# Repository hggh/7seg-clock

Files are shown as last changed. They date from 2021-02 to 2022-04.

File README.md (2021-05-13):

# seven segment clock with ambilight

 * 58x WS2812b 
 * ESP32
 * 74AHC125
 * XC6220 3.0V

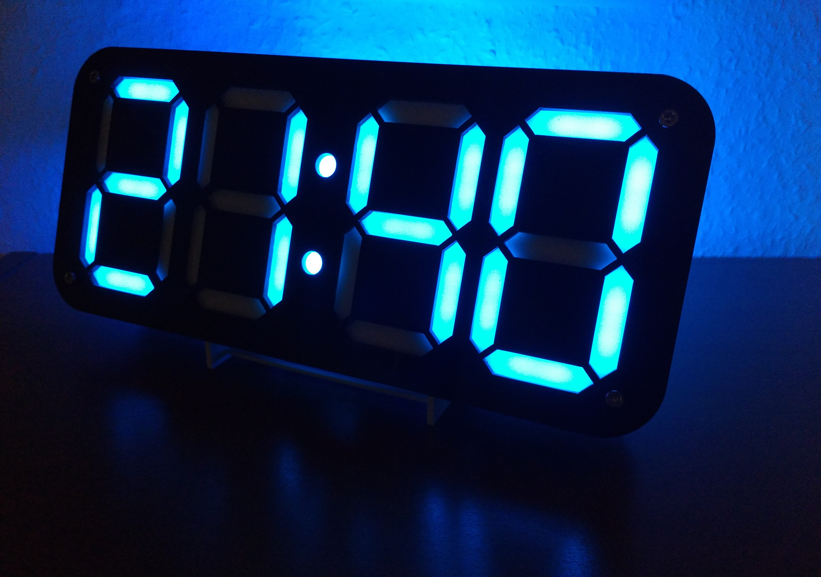
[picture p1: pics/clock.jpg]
7 Seg Clock 7 seg clock


To control the WS2812b LEDs the clock controller from wood clock light is used: https://github.com/hggh/wood-clock-light/tree/master/pcb/esp32-clock-base

### the base pcb for all ws2812b

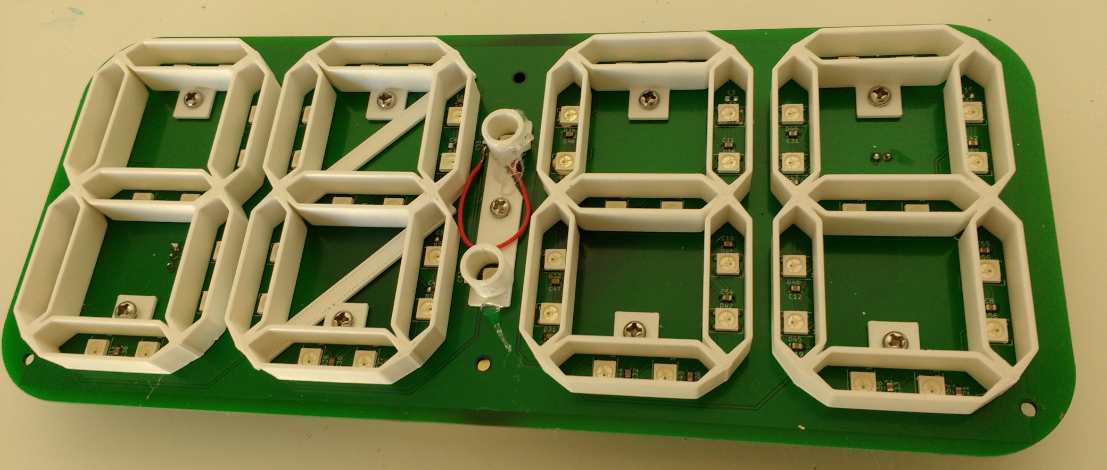
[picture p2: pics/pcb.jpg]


### ESP32 to control all LEDs

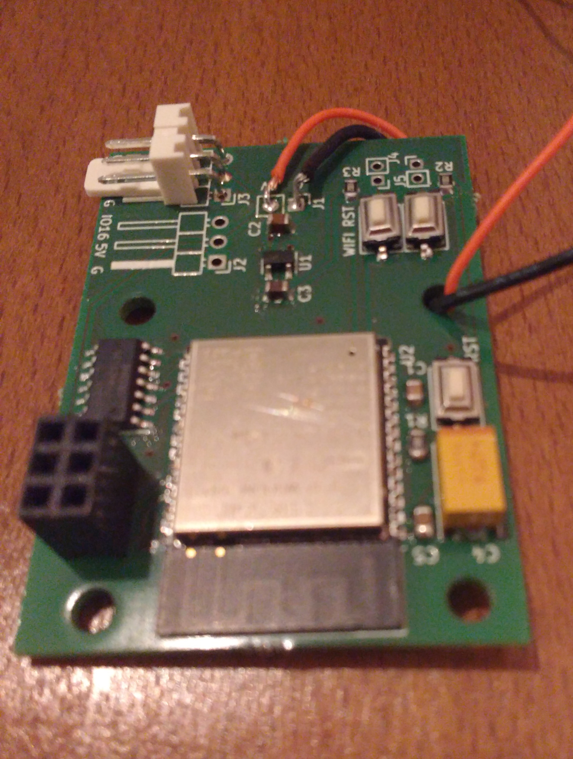
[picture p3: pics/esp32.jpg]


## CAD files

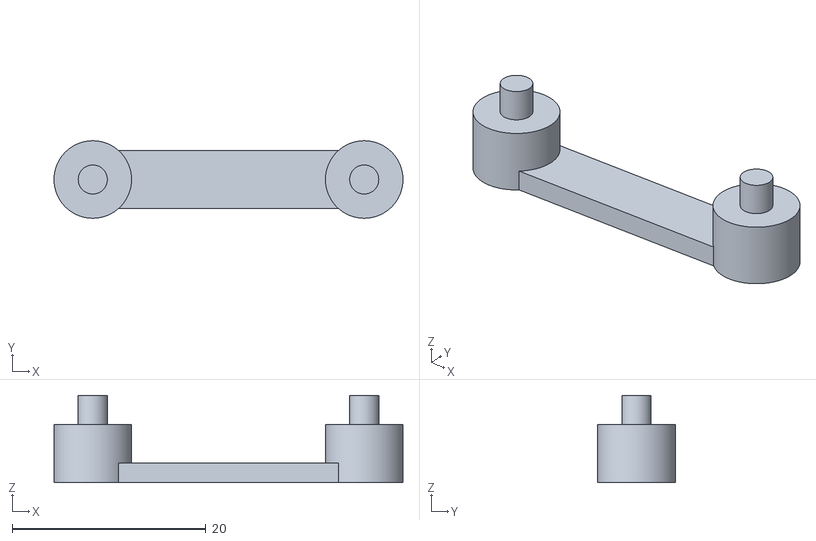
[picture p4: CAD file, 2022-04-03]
case/pcb-holder.stl
36.0 x 8.00 x 9.00

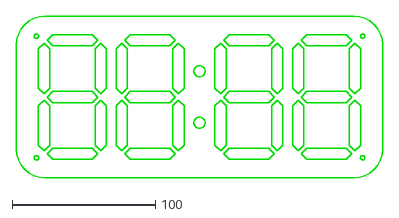
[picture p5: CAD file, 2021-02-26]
case/plexiglas-output/black_base_3mm.dxf
256.0 x 113.0

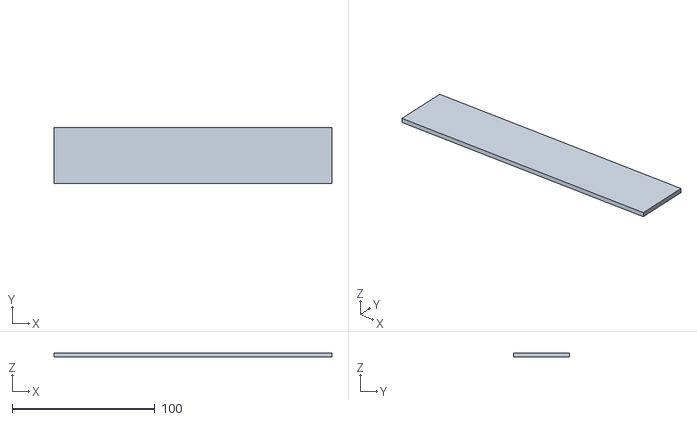
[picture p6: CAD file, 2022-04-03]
case/bottom.stl
195.0 x 39.0 x 3.00

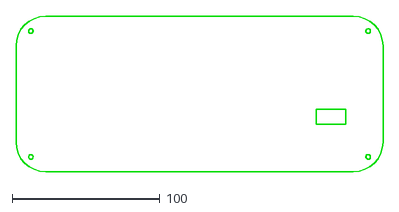
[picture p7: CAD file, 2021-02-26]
case/plexiglas-output/black_back_case_3mm.dxf
248.0 x 105.0

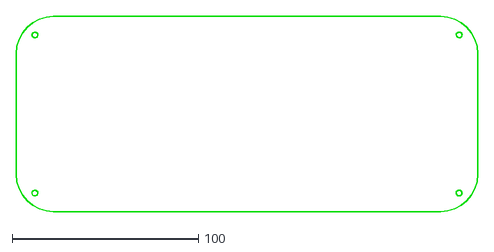
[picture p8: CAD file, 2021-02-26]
case/plexiglas-output/white_opal_3mm.dxf
248.0 x 105.0

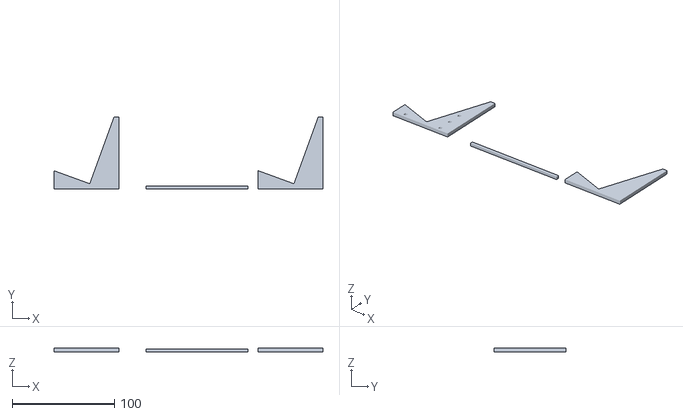
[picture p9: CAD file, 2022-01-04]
case/stand.stl
263.5 x 70.2 x 3.70

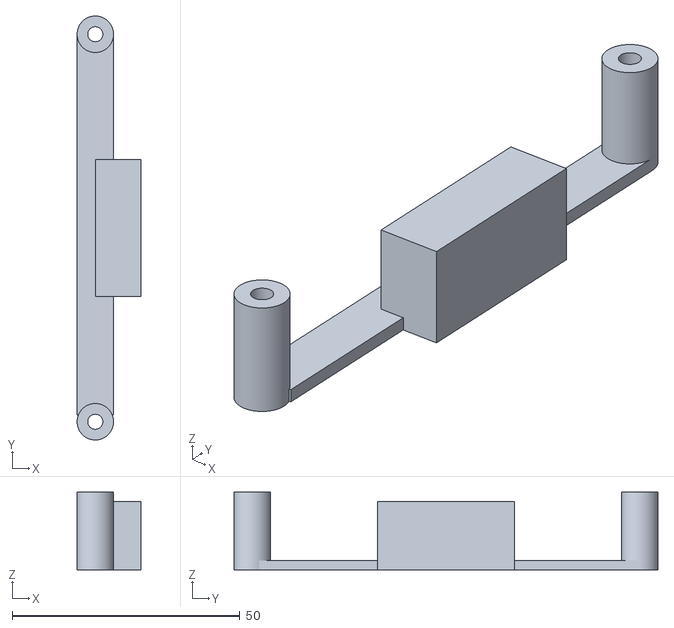
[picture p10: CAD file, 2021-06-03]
case/holder-case-wall.stl
14.0 x 93.0 x 17.0

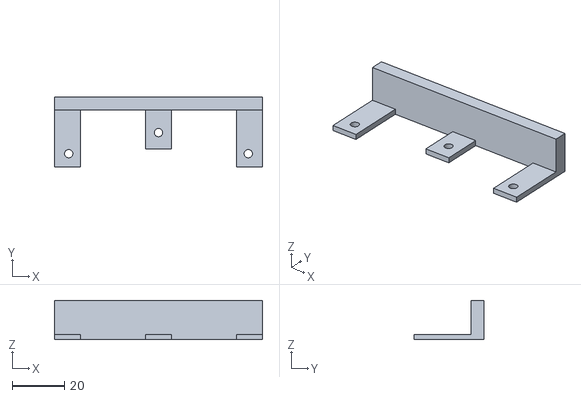
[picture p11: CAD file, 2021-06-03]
case/wall_mount_top.stl
80.0 x 27.0 x 15.0

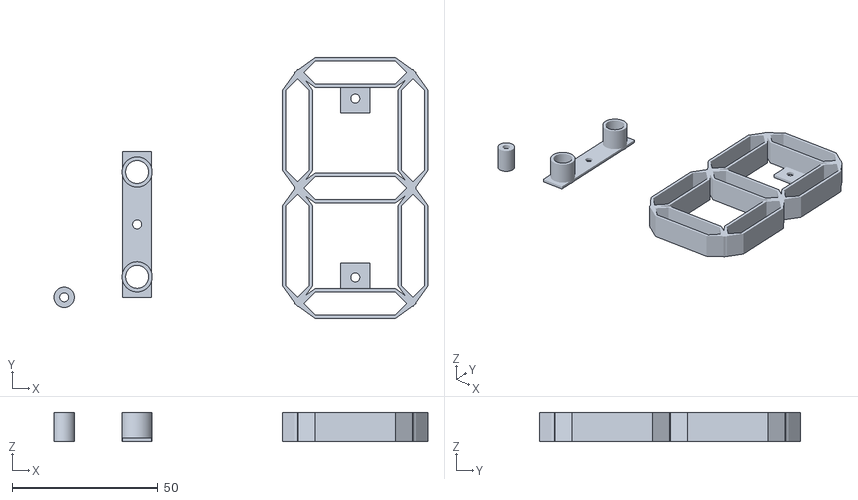
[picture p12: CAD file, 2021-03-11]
case/spacing.stl
128.2 x 89.4 x 10.0

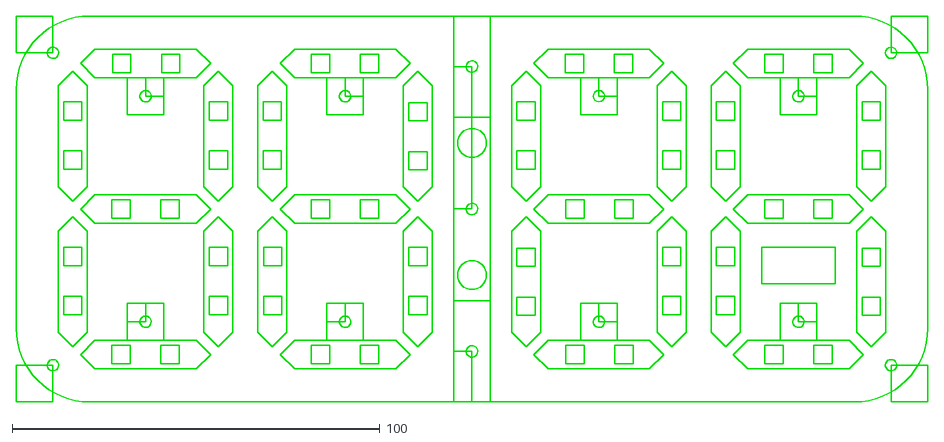
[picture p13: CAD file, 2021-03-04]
case/clock-base-for-kicad.dxf
248.0 x 105.0

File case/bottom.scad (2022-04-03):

cube([195, 39, 3]);

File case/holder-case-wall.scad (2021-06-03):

module base() {
    cylinder(d=8, h=17, $fn=190);
    translate([0, 85, 0]) {
        cylinder(d=8, h=17, $fn=190);
    }
    translate([-4, 1.5, 0]) {
        cube([8, 85 - 1.5, 2]);
    }
    difference() {
        translate([0, 85/2 - 15, 0]) {
            cube([10, 30, 15]);
        }
    }
}


difference() {
    base();
    cylinder(d=3.3, h=20, $fn=190);
    translate([0, 85, 0]) {
        cylinder(d=3.3, h=20, $fn=190);
    }
}

module spacing_screws_back() {
    difference() {
        cylinder(d=8, h=17, $fn=190);
        cylinder(d=3.3, h=20, $fn=190);
    }
    translate([0, 85, 0]) {
        difference() {
            cylinder(d=8, h=17, $fn=190);
            cylinder(d=3.3, h=20, $fn=190);
        }
    }
}

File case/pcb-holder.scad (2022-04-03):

$fn=190;


translate([-2, -3, 0])
    cube([30, 6, 2]);
cylinder(d=8, h=6);
cylinder(d=3, h=9);
translate([28, 0, 0]) {
    cylinder(d=8, h=6);
    cylinder(d=3, h=9);
}

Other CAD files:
case/spacing.scad
case/stand.scad
case/wall_mount_top.scad

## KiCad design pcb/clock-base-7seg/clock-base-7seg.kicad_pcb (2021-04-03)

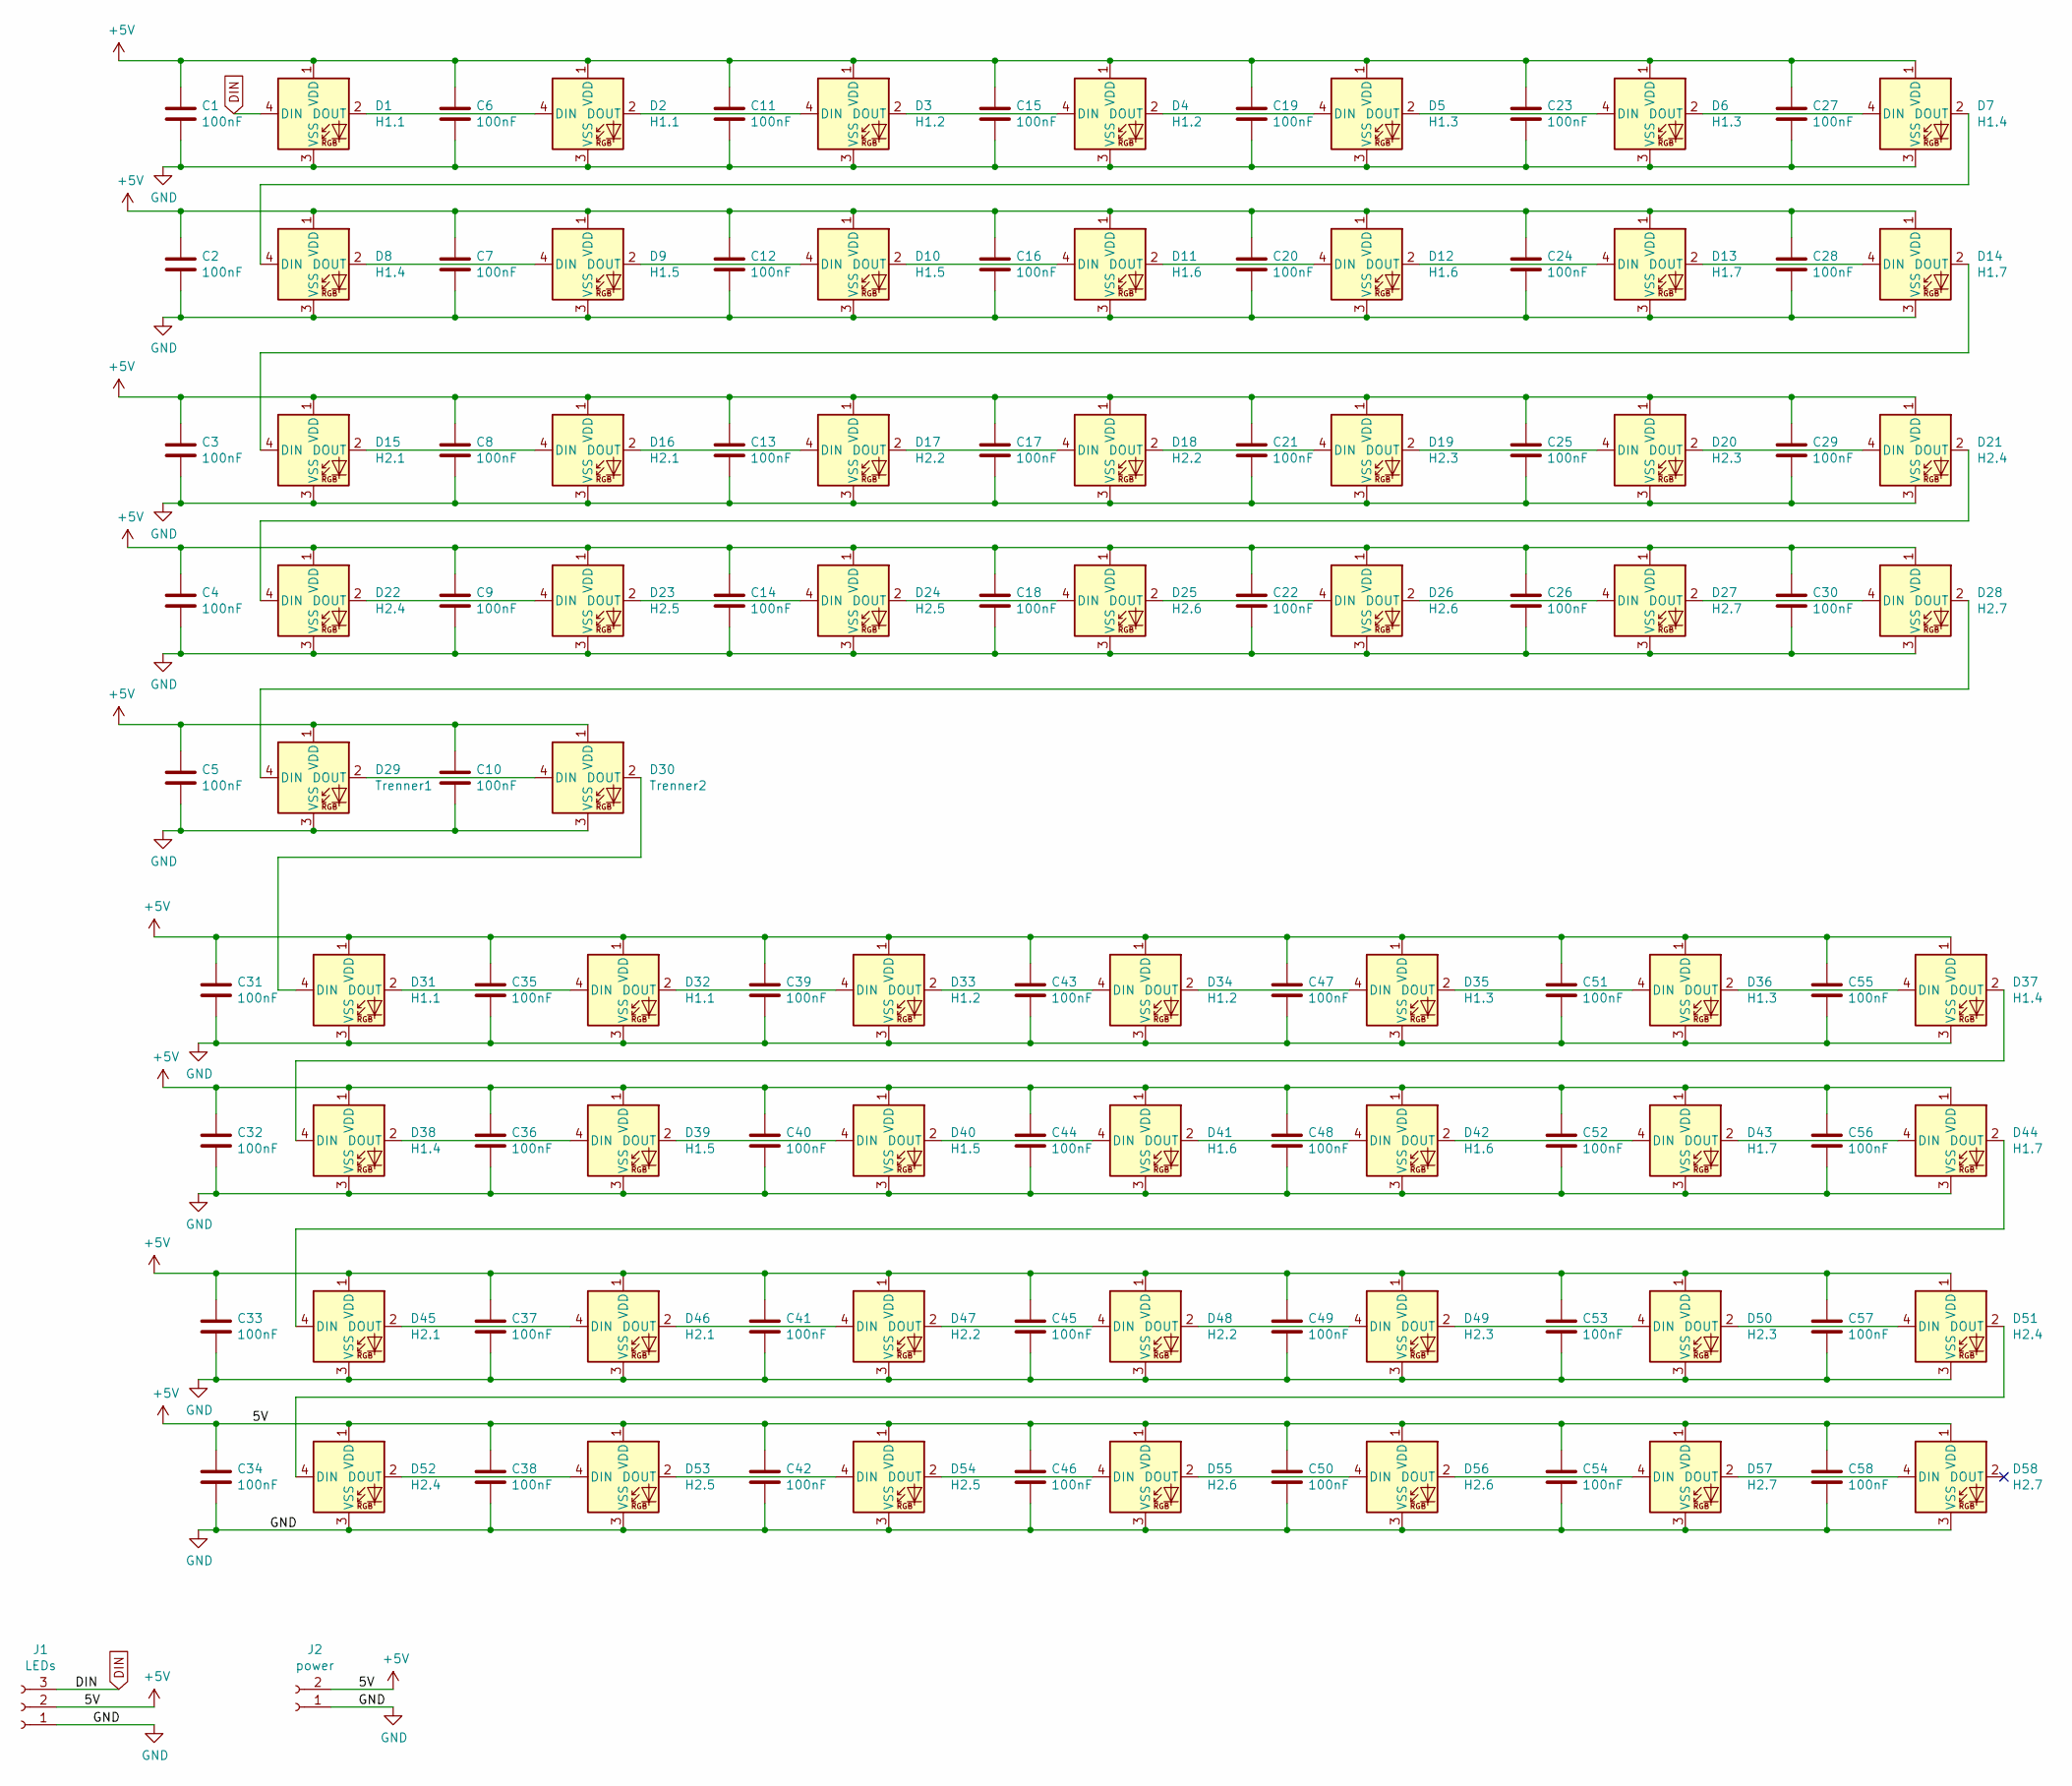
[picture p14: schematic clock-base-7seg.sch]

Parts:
C1, C2, C3, C4, C5, C6, C7, C8, C9, C10, C11, C12, C13, C14, C15, C16, C17, C18, C19, C20, C21, C22, C23, C24, C25, C26, C27, C28, C29, C30, C31, C32, C33, C34, C35, C36, C37, C38, C39, C40, C41, C42, C43, C44, C45, C46, C47, C48, C49, C50, C51, C52, C53, C54, C55, C56, C57, C58: 100nF; C_0805_2012Metric_Pad1.18x1.45mm_HandSolder
D1, D2, D31, D32: H1.1; LED_WS2812B_PLCC4_5.0x5.0mm_P3.2mm
D3, D4, D33, D34: H1.2; LED_WS2812B_PLCC4_5.0x5.0mm_P3.2mm
D5, D6, D35, D36: H1.3; LED_WS2812B_PLCC4_5.0x5.0mm_P3.2mm
D7, D8, D37, D38: H1.4; LED_WS2812B_PLCC4_5.0x5.0mm_P3.2mm
D9, D10, D39, D40: H1.5; LED_WS2812B_PLCC4_5.0x5.0mm_P3.2mm
D11, D12, D41, D42: H1.6; LED_WS2812B_PLCC4_5.0x5.0mm_P3.2mm
D13, D14, D43, D44: H1.7; LED_WS2812B_PLCC4_5.0x5.0mm_P3.2mm
D15, D16, D45, D46: H2.1; LED_WS2812B_PLCC4_5.0x5.0mm_P3.2mm
D17, D18, D47, D48: H2.2; LED_WS2812B_PLCC4_5.0x5.0mm_P3.2mm
D19, D20, D49, D50: H2.3; LED_WS2812B_PLCC4_5.0x5.0mm_P3.2mm
D21, D22, D51, D52: H2.4; LED_WS2812B_PLCC4_5.0x5.0mm_P3.2mm
D23, D24, D53, D54: H2.5; LED_WS2812B_PLCC4_5.0x5.0mm_P3.2mm
D25, D26, D55, D56: H2.6; LED_WS2812B_PLCC4_5.0x5.0mm_P3.2mm
D27, D28, D57, D58: H2.7; LED_WS2812B_PLCC4_5.0x5.0mm_P3.2mm
D29: Trenner1; LED_WS2812B_PLCC4_5.0x5.0mm_P3.2mm
D30: Trenner2; LED_WS2812B_PLCC4_5.0x5.0mm_P3.2mm
J1: LEDs; PinHeader_1x03_P2.54mm_Vertical
J2: power; PinHeader_1x02_P2.54mm_Vertical

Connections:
+5V: C1.1, C2.1, C3.1, C4.1, C5.1, C6.1, C7.1, C8.1, C9.1, C10.1, C11.1, C12.1, C13.1, C14.1, C15.1, C16.1, C17.1, C18.1, C19.1, C20.1, C21.1, C22.1, C23.1, C24.1, C25.1, C26.1, C27.1, C28.1, C29.1, C30.1, C31.1, C32.1, C33.1, C34.1, C35.1, C36.1, C37.1, C38.1, C39.1, C40.1, C41.1, C42.1, C43.1, C44.1, C45.1, C46.1, C47.1, C48.1, C49.1, C50.1, C51.1, C52.1, C53.1, C54.1, C55.1, C56.1, C57.1, C58.1, D1.1 (VDD), D2.1 (VDD), D3.1 (VDD), D4.1 (VDD), D5.1 (VDD), D6.1 (VDD), D7.1 (VDD), D8.1 (VDD), D9.1 (VDD), D10.1 (VDD), D11.1 (VDD), D12.1 (VDD), D13.1 (VDD), D14.1 (VDD), D15.1 (VDD), D16.1 (VDD), D17.1 (VDD), D18.1 (VDD), D19.1 (VDD), D20.1 (VDD), D21.1 (VDD), D22.1 (VDD), D23.1 (VDD), D24.1 (VDD), D25.1 (VDD), D26.1 (VDD), D27.1 (VDD), D28.1 (VDD), D29.1 (VDD), D30.1 (VDD), D31.1 (VDD), D32.1 (VDD), D33.1 (VDD), D34.1 (VDD), D35.1 (VDD), D36.1 (VDD), D37.1 (VDD), D38.1 (VDD), D39.1 (VDD), D40.1 (VDD), D41.1 (VDD), D42.1 (VDD), D43.1 (VDD), D44.1 (VDD), D45.1 (VDD), D46.1 (VDD), D47.1 (VDD), D48.1 (VDD), D49.1 (VDD), D50.1 (VDD), D51.1 (VDD), D52.1 (VDD), D53.1 (VDD), D54.1 (VDD), D55.1 (VDD), D56.1 (VDD), D57.1 (VDD), D58.1 (VDD), J1.2, J2.2
DIN: D1.4 (DIN), J1.3
GND: C1.2, C2.2, C3.2, C4.2, C5.2, C6.2, C7.2, C8.2, C9.2, C10.2, C11.2, C12.2, C13.2, C14.2, C15.2, C16.2, C17.2, C18.2, C19.2, C20.2, C21.2, C22.2, C23.2, C24.2, C25.2, C26.2, C27.2, C28.2, C29.2, C30.2, C31.2, C32.2, C33.2, C34.2, C35.2, C36.2, C37.2, C38.2, C39.2, C40.2, C41.2, C42.2, C43.2, C44.2, C45.2, C46.2, C47.2, C48.2, C49.2, C50.2, C51.2, C52.2, C53.2, C54.2, C55.2, C56.2, C57.2, C58.2, D1.3 (VSS), D2.3 (VSS), D3.3 (VSS), D4.3 (VSS), D5.3 (VSS), D6.3 (VSS), D7.3 (VSS), D8.3 (VSS), D9.3 (VSS), D10.3 (VSS), D11.3 (VSS), D12.3 (VSS), D13.3 (VSS), D14.3 (VSS), D15.3 (VSS), D16.3 (VSS), D17.3 (VSS), D18.3 (VSS), D19.3 (VSS), D20.3 (VSS), D21.3 (VSS), D22.3 (VSS), D23.3 (VSS), D24.3 (VSS), D25.3 (VSS), D26.3 (VSS), D27.3 (VSS), D28.3 (VSS), D29.3 (VSS), D30.3 (VSS), D31.3 (VSS), D32.3 (VSS), D33.3 (VSS), D34.3 (VSS), D35.3 (VSS), D36.3 (VSS), D37.3 (VSS), D38.3 (VSS), D39.3 (VSS), D40.3 (VSS), D41.3 (VSS), D42.3 (VSS), D43.3 (VSS), D44.3 (VSS), D45.3 (VSS), D46.3 (VSS), D47.3 (VSS), D48.3 (VSS), D49.3 (VSS), D50.3 (VSS), D51.3 (VSS), D52.3 (VSS), D53.3 (VSS), D54.3 (VSS), D55.3 (VSS), D56.3 (VSS), D57.3 (VSS), D58.3 (VSS), J1.1, J2.1
unnamed: D1.2 (DOUT), D2.4 (DIN)
unnamed: D2.2 (DOUT), D3.4 (DIN)
unnamed: D3.2 (DOUT), D4.4 (DIN)
unnamed: D4.2 (DOUT), D5.4 (DIN)
unnamed: D5.2 (DOUT), D6.4 (DIN)
unnamed: D6.2 (DOUT), D7.4 (DIN)
unnamed: D7.2 (DOUT), D8.4 (DIN)
unnamed: D8.2 (DOUT), D9.4 (DIN)
unnamed: D10.2 (DOUT), D11.4 (DIN)
unnamed: D9.2 (DOUT), D10.4 (DIN)
unnamed: D11.2 (DOUT), D12.4 (DIN)
unnamed: D12.2 (DOUT), D13.4 (DIN)
unnamed: D13.2 (DOUT), D14.4 (DIN)
unnamed: D14.2 (DOUT), D15.4 (DIN)
unnamed: D15.2 (DOUT), D16.4 (DIN)
unnamed: D16.2 (DOUT), D17.4 (DIN)
unnamed: D17.2 (DOUT), D18.4 (DIN)
unnamed: D18.2 (DOUT), D19.4 (DIN)
unnamed: D19.2 (DOUT), D20.4 (DIN)
unnamed: D20.2 (DOUT), D21.4 (DIN)
unnamed: D21.2 (DOUT), D22.4 (DIN)
unnamed: D22.2 (DOUT), D23.4 (DIN)
unnamed: D23.2 (DOUT), D24.4 (DIN)
unnamed: D24.2 (DOUT), D25.4 (DIN)
unnamed: D25.2 (DOUT), D26.4 (DIN)
unnamed: D26.2 (DOUT), D27.4 (DIN)
unnamed: D27.2 (DOUT), D28.4 (DIN)
unnamed: D28.2 (DOUT), D29.4 (DIN)
unnamed: D29.2 (DOUT), D30.4 (DIN)
unnamed: D30.2 (DOUT), D31.4 (DIN)
unnamed: D31.2 (DOUT), D32.4 (DIN)
unnamed: D32.2 (DOUT), D33.4 (DIN)
unnamed: D33.2 (DOUT), D34.4 (DIN)
unnamed: D34.2 (DOUT), D35.4 (DIN)
unnamed: D35.2 (DOUT), D36.4 (DIN)
unnamed: D36.2 (DOUT), D37.4 (DIN)
unnamed: D37.2 (DOUT), D38.4 (DIN)
unnamed: D38.2 (DOUT), D39.4 (DIN)
unnamed: D39.2 (DOUT), D40.4 (DIN)
unnamed: D40.2 (DOUT), D41.4 (DIN)
unnamed: D41.2 (DOUT), D42.4 (DIN)
unnamed: D42.2 (DOUT), D43.4 (DIN)
unnamed: D43.2 (DOUT), D44.4 (DIN)
unnamed: D44.2 (DOUT), D45.4 (DIN)
unnamed: D45.2 (DOUT), D46.4 (DIN)
unnamed: D46.2 (DOUT), D47.4 (DIN)
unnamed: D47.2 (DOUT), D48.4 (DIN)
unnamed: D48.2 (DOUT), D49.4 (DIN)
unnamed: D49.2 (DOUT), D50.4 (DIN)
unnamed: D50.2 (DOUT), D51.4 (DIN)
unnamed: D51.2 (DOUT), D52.4 (DIN)
unnamed: D52.2 (DOUT), D53.4 (DIN)
unnamed: D53.2 (DOUT), D54.4 (DIN)
unnamed: D54.2 (DOUT), D55.4 (DIN)
unnamed: D55.2 (DOUT), D56.4 (DIN)
unnamed: D56.2 (DOUT), D57.4 (DIN)
unnamed: D57.2 (DOUT), D58.4 (DIN)

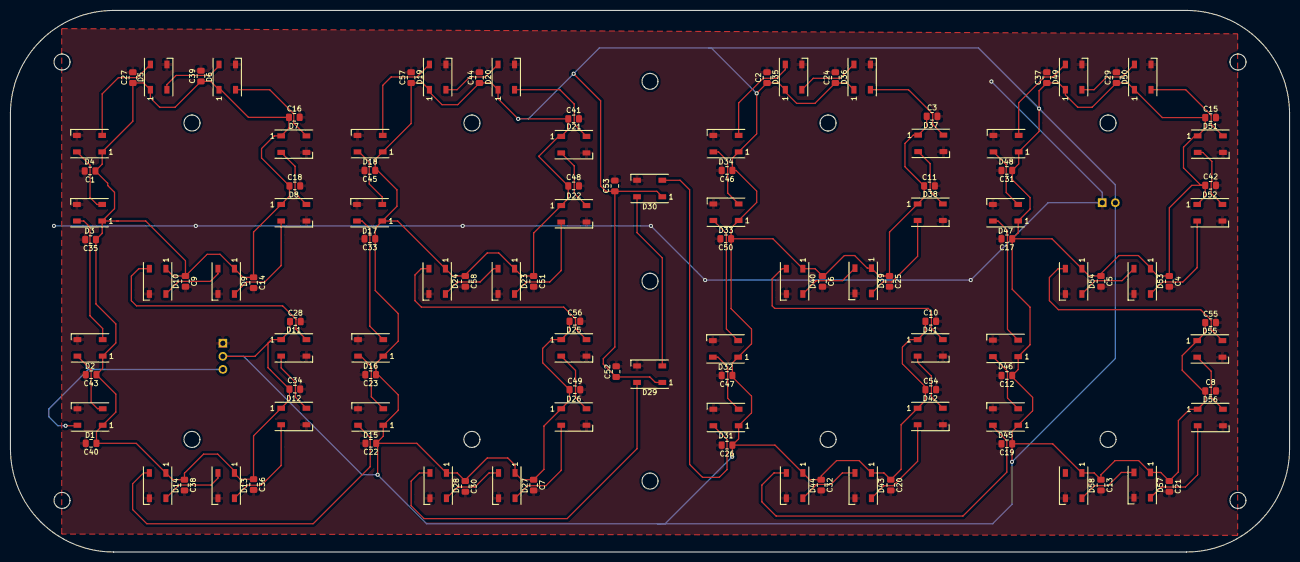
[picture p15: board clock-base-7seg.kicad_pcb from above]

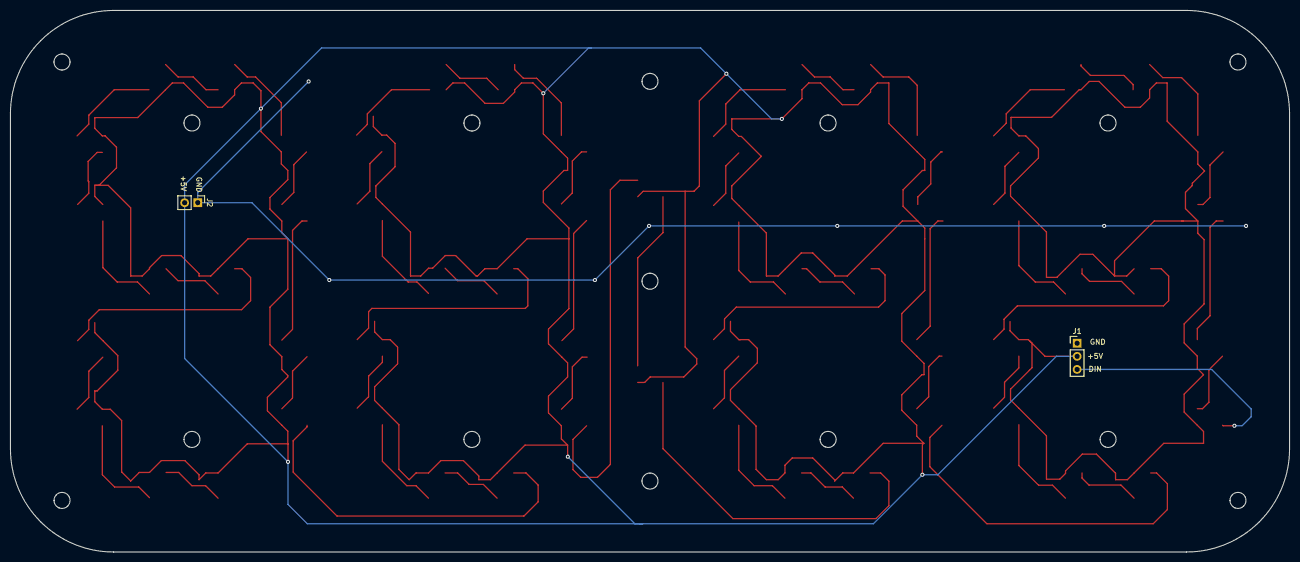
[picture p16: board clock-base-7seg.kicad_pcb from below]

Board: 2 copper layers, 248.0 x 105.0 mm, 118 parts (2 on the bottom side), 60 nets.

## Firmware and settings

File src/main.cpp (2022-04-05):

#include <Arduino.h>
#include "SPIFFS.h"
#include <WiFi.h>
#include <ESPmDNS.h>
#include <time.h>

#include <FS.h>
#include <FastLED.h>
#include <Bounce2.h>
#include <WiFiManager.h>
#include <WebServer.h>
#include <ArduinoJson.h>

#include "numbers.h"

#define LED_COUNT 58
#define PIN_RGB_LEDS 17
#define PIN_WIFI_RESET 34
#define HOSTNAME "clocki-7seg"
#define uS_TO_S_FACTOR 1000000ULL

CRGB leds[LED_COUNT];
CRGB led_color = CRGB::Blue;
String html_color_code = "#0039e6";
bool update_leds = false;

WebServer server(80);
WiFiManager wm;
Bounce2::Button wifi_cfg_reset = Bounce2::Button();

const long gmt_offset_sec = -3600;
const int day_light_offset_sec = 3600;

uint8_t time_hour = 255;
uint8_t time_minute = 255;

struct Config{
  uint8_t led_brightness;
  char color[10];
  bool time_sleep_enable;
  uint8_t time_sleep_hour;
  uint8_t time_sleep_duration;
};
Config config;

void fill_color_from_config(Config &config) {
  String ctmp = String(config.color);
  ctmp.replace("#", "");
  long color_code = strtol(ctmp.c_str(), NULL, 16);
  led_color = CRGB(color_code);
}

void load_configuration(Config &config) {
  File file = SPIFFS.open("/esp32-config.txt");
  StaticJsonDocument<300> doc;
  DeserializationError error = deserializeJson(doc, file);
  if (error) {
    Serial.println(F("Failed to read file, using default configuration"));
  }
  config.led_brightness = doc["led_brightness"] | 70;
  strlcpy(config.color, doc["color"] | "#89CFF0", sizeof(config.color));
  config.time_sleep_enable = doc["time_sleep_enable"] | false;
  config.time_sleep_hour = doc["time_sleep_hour"] | 22;
  config.time_sleep_duration = doc["time_sleep_duration"] | 8;

  fill_color_from_config(config);

  if (serializeJson(doc, file) == 0) {
    Serial.println(F("Failed to write to file"));
  }
  file.close();
}

void save_configuration(Config &config) {
  SPIFFS.remove("/esp32-config.txt");
  File file = SPIFFS.open("/esp32-config.txt", FILE_WRITE);

  StaticJsonDocument<300> doc;
  doc["led_brightness"] = config.led_brightness;
  doc["color"] = config.color;

  doc["time_sleep_enable"] = config.time_sleep_enable;
  doc["time_sleep_hour"] = config.time_sleep_hour;
  doc["time_sleep_duration"] = config.time_sleep_duration;

  fill_color_from_config(config);

  if (serializeJson(doc, file) == 0) {
    Serial.println(F("Failed to write to file"));
  }
  file.close();
}

void write_number_to_leds(uint8_t offset, uint8_t number) {
  for (uint8_t i = 0; i < 14; i++) {
    if (numbers[number][i] == 1) {
      leds[offset + i] = led_color;
    }
  }
}

void clock_display_number(uint8_t offset, uint8_t number, boolean display_zero = false) {
  uint8_t t_first = ((number / 10 ) % 10);
  uint8_t t_second = (number % 10 );

  if (display_zero == true || t_first != 0 ) {
    write_number_to_leds(offset, t_first);
  }
  write_number_to_leds(offset + 14, t_second);
}


void webHandleRoot() {
  String content = "";
  File file = SPIFFS.open("/index.html");
  while(file.available()){
    content += char(file.read());
  }
  content.replace("LED_BRIGHTNESS_VALUE", String(config.led_brightness));
  content.replace("LED_SINGLE_COLOR_CODE", String(config.color));
  if (config.time_sleep_enable == true) {
    content.replace("TIME_SLEEP_ENABLE", String("enable"));
  }
  else {
    content.replace("TIME_SLEEP_ENABLE", String("disable"));
  }
  content.replace("TIME_SLEEP_HOUR", String(config.time_sleep_hour));
  content.replace("TIME_SLEEP_DURATION", String(config.time_sleep_duration));

  file.close();
  server.send(200, "text/html", content);
}

void webHandleUpdate() {
  String req_color_single = server.arg("color");
  req_color_single.toCharArray(config.color, 10);

  String req_brightness = server.arg("brightness");
  config.led_brightness = req_brightness.toInt();

  String req_time_sleep_enable = server.arg("time_sleep_enable");
  if (req_time_sleep_enable.equals("enable")) {
    config.time_sleep_enable = true;
  }
  else {
    config.time_sleep_enable = false;
  }

  String req_time_sleep_hour = server.arg("time_sleep_hour");
  config.time_sleep_hour =  req_time_sleep_hour.toInt();

  String req_time_sleep_duration = server.arg("time_sleep_duration");
  config.time_sleep_duration =  req_time_sleep_duration.toInt();

  FastLED.setBrightness(config.led_brightness);
  save_configuration(config);

  update_leds = true;
  webHandleRoot();
}


void wm_config_mode_callback(WiFiManager *myWiFiManager) {
  Serial.println("Entering WiFI Manager configuration....");

  fill_solid(leds, LED_COUNT, CRGB::DeepPink);
  FastLED.show();
}

void goto_sleep(unsigned int hours = 1) {
  Serial.println("Goto sleep...");
  FastLED.clear(true);
  esp_wifi_stop();
  delay(10);
  esp_sleep_enable_timer_wakeup((uint64_t)(hours * 60 * 60) * (uint64_t)uS_TO_S_FACTOR);
  esp_deep_sleep_start();
}

void setup() {
  btStop();
  WiFi.mode(WIFI_STA);
  WiFi.setHostname(HOSTNAME);
  Serial.begin(115200);

  FastLED.addLeds<NEOPIXEL, PIN_RGB_LEDS>(leds, LED_COUNT);

  if(!SPIFFS.begin(true)){
    Serial.println("error on SPIFFS...");
  }
  std::vector<const char *> wm_menu  = {"wifi", "exit"};
  wm.setConnectTimeout(30);
  wm.setAPCallback(wm_config_mode_callback);
  wm.setShowInfoUpdate(true);
  wm.setShowInfoErase(false);
  wm.setMenu(wm_menu);
  wm.autoConnect(HOSTNAME, "");

  load_configuration(config);

  FastLED.setBrightness(config.led_brightness);
  fill_solid(leds, LED_COUNT, CRGB::Black);
  FastLED.show();

  server.on("/", webHandleRoot);
  server.on("/update", webHandleUpdate);
  server.begin();

  MDNS.begin(HOSTNAME);
  MDNS.addService("http", "tcp", 80);
  configTime(gmt_offset_sec, day_light_offset_sec, "0.de.pool.ntp.org", "1.de.pool.ntp.org", "2.de.pool.ntp.org");
  setenv("TZ", "CET-1CEST,M3.5.0,M10.5.0/3", 1);
  tzset();

  wifi_cfg_reset.attach(PIN_WIFI_RESET, INPUT);
  wifi_cfg_reset.interval(25);
  wifi_cfg_reset.setPressedState(LOW);
}

void loop() {
  wifi_cfg_reset.update();
  server.handleClient();

  if (wifi_cfg_reset.pressed()) {
    // WiFi reset configuration button was pressed
    wm.resetSettings();
    Serial.println("WiFi reset configuration button was pressed......");
    Serial.flush();
    delay(500);
    ESP.restart();
  }

  if (WiFi.status() != WL_CONNECTED) {
    wm.autoConnect(HOSTNAME, "");
  }

  struct tm timedate;
  getLocalTime(&timedate);

  if (timedate.tm_min != time_minute || timedate.tm_hour != time_hour || update_leds == true) {
    update_leds = false;
    // time has changed, display it on the WS2812b LEDs
    time_minute = timedate.tm_min;
    time_hour = timedate.tm_hour;
    fill_solid(leds, LED_COUNT, CRGB::Black);

    if (time_hour == 0) {
      clock_display_number(0, time_hour, true);
    }
    else {
      clock_display_number(0, time_hour, false);
    }
    clock_display_number(30, time_minute, true);

    // dots
    leds[28] = led_color;
    leds[29] = led_color;

    FastLED.show();
  }
  if (config.time_sleep_enable == true && config.time_sleep_hour == timedate.tm_hour && timedate.tm_min == 0) {
    goto_sleep(config.time_sleep_duration);
  }
  delay(1);
}

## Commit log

2021-02-22 add artwork, pcb, code
    [clock-base-7seg.kicad_pcb, clock-base-7seg.sch, clock-base-for-kicad.dxf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]
2021-02-26 update case and fabric output
    [black_back_case_3mm.dxf, black_base_3mm.dxf, black_wall_3mm.dxf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]
2021-02-27 update final prod data
    [clock-base-for-kicad.dxf]
2021-02-27 work on the clock code; wifi reset, using wifi manager and Bounce for a Reset Button
    [main.cpp]
2021-03-04 update pcb
    [clock-base-7seg.kicad_pcb, clock-base-7seg.sch, clock-base-for-kicad.dxf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]
2021-03-05 add usb holder
    [usb_holder.scad, usb_holder.stl]
2021-03-11 add spacing
    [spacing.scad, spacing.stl]
2021-04-03 bigger spacing
    [spacing.scad]
2021-04-03 finalize pcb
    [clock-base-7seg.kicad_pcb, clock-base-7seg.sch]
2021-04-03 add washer
    [spacing.scad]
2021-04-29 removed old pcb
    [clock-controller.kicad_pcb, clock-controller.sch]
2021-05-07 spacing for back over
    [spacing.scad]
2021-05-10 add stand
    [stand.scad]
2021-05-14 pin 34 has no pullup
2021-05-16 not the corect size
    [black_wall_3mm.dxf]
2021-05-21 moved to extra file
    [spacing.scad]
2021-06-03 add holder to stick wall to frame
    [holder-case-wall.scad, holder-case-wall.stl, wall_mount_top.scad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]
2021-06-03 no screws just glue the black plexiglas wall
    [holder-case-wall.scad, holder-case-wall.stl]
2022-01-04 update stand to more robust version
    [stand.scad, stand.stl]
2022-04-03 add pcb holder, add bottom part, update to webserver with html file
    [bottom.scad, bottom.stl, pcb-holder.scad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]
2022-04-05 add sleep timer start
